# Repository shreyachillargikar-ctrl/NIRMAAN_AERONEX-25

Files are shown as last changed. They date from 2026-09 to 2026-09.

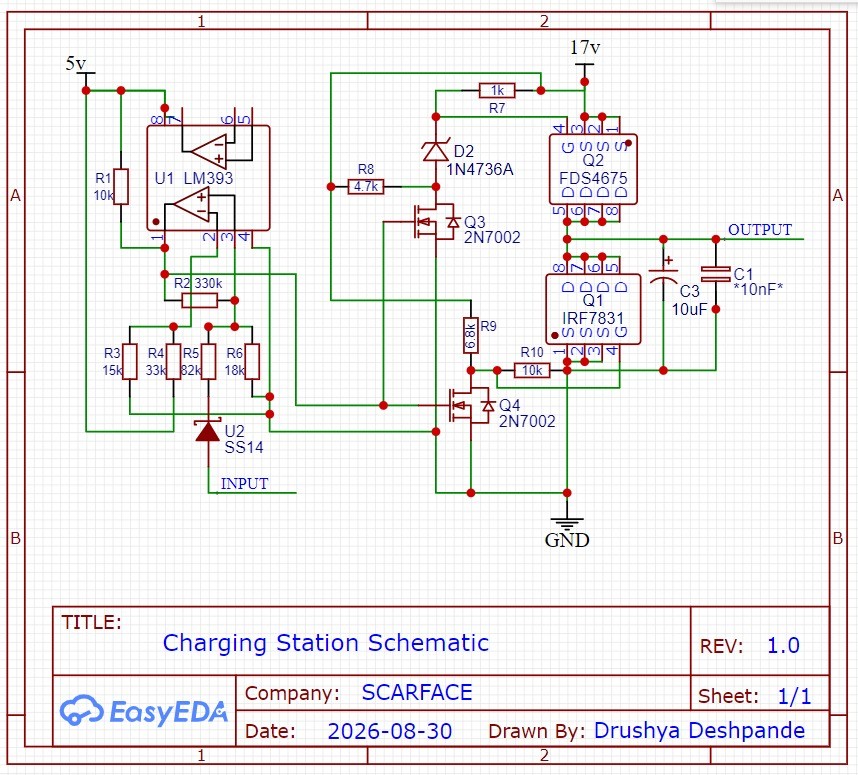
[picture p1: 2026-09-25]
Hardware/Circuit_Diagram/CIRCUIT DIAGRAM.jpeg

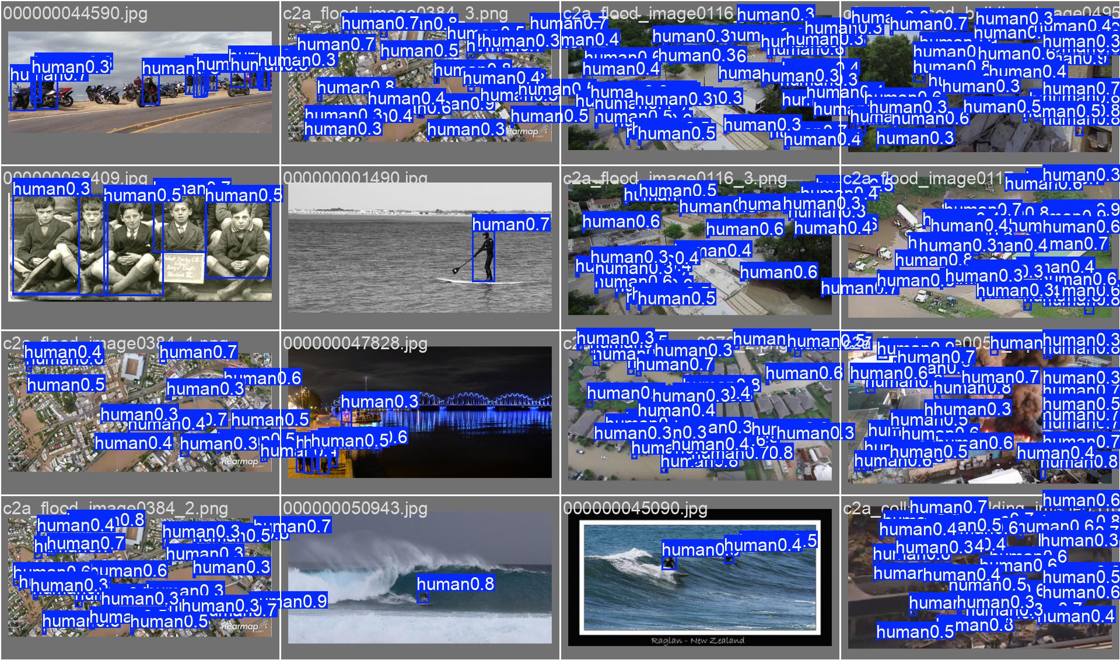
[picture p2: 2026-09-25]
Software/AI model/Trained_YOLOV8s/val_batch0_pred.jpg

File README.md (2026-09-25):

#  NIRMAAN_AERONEX-26

## AI-POWERED SEARCH AND RESCUE OPERATION DRONE

### NIRMAAN 2026
**Build. Innovate. Impact.**

---

##  TEAM INFORMATION

**Team Name:** NIRMAAN_AERONEX-26

**Team Leader:** ASHWATH YADAV

**Chosen Track:** Smart Mobility & Aerospace

**Problem Statement:**  
Development of an AI-powered aerial search and rescue system capable of assisting rescue teams in locating and identifying people in emergency and disaster situations.

---

# 1.  PROBLEM STATEMENT & REAL-WORLD IMPACT

## The Problem

During natural disasters, accidents, building collapses, floods, fires, and other emergency situations, locating people quickly can be difficult and dangerous.

Traditional search and rescue operations may require:

- Large numbers of rescue personnel
- Significant time to cover large areas
- Access to difficult or unsafe terrain
- Manual visual inspection
- Continuous communication between field teams

Areas with limited accessibility can significantly increase the time required to locate survivors.

### Why aerial assistance is required

A drone can provide:

- Rapid aerial coverage
- Access to difficult terrain
- Real-time aerial observation
- Reduced risk to human rescuers
- Faster identification of potential survivors

---

## Target Audience

The proposed system is intended to assist:

- Search and rescue teams
- Disaster response teams
- Emergency response organizations
- Fire and rescue departments
- Disaster management authorities
- Humanitarian response teams

---

## Current Gaps & Impact

### Current Gaps

Existing manual search operations can face:

- Limited area coverage
- Dependence on human visual inspection
- Difficult terrain accessibility
- Increased search time
- Risk to rescue personnel
- Difficulty maintaining continuous aerial surveillance

### Impact

AERONEX aims to support rescue operations by providing an aerial platform capable of:

**SEARCH → DETECT → LOCATE → REPORT**

This can help rescue personnel make faster and more informed decisions during emergency situations.

---

# 2. PROPOSED SOLUTION & INNOVATION

## Core Solution

AERONEX is an AI-powered search and rescue drone that combines:

- Autonomous flight
- GPS-based navigation
- Aerial imaging
- AI-based human detection
- Real-time telemetry
- Flight-controller-based stabilization
- Long-range radio communication

The drone is designed to autonomously navigate a defined search area while the onboard camera and AI processing system assist in identifying potential humans.

---

## Innovation Factor

The key innovation of AERONEX is the integration of an autonomous aerial platform with AI-based human detection for search and rescue applications.

Instead of relying entirely on manual visual inspection, the system is designed to assist in identifying potential survivors from aerial imagery.

### Innovation Highlights

- AI-assisted human detection
- Autonomous waypoint navigation
- GPS-based positioning
- Real-time telemetry
- Onboard mobile computing using a smartphone
- Integrated aerial surveillance
- Modular and scalable hardware architecture
- Customised Battery
- Automated charging Station 
---

# 3.  KEY FEATURES

###  Autonomous Navigation

The drone uses a flight controller and GPS system for autonomous waypoint-based navigation.

###  AI-Based Human Detection

The camera system provides aerial images/video for AI-based detection of people in the search area.

###  GPS Positioning

GPS provides location information required for navigation and mission planning.

###  Real-Time Telemetry

Telemetry enables communication between the ground station and the drone for monitoring flight and mission information.

###  Aerial Surveillance

The onboard camera provides an aerial view of the search environment.

###  Manual Override

The radio transmitter and receiver provide manual control capability when required.

###  Stable Flight Platfor

## System Architecture

```mermaid
flowchart TB

A[SEARCH AND RESCUE MISSION]
B[GROUND CONTROL STATION]
C[PIXHAWK 2.4.8 FLIGHT CONTROLLER]

A --> B
B -->|MISSION PLAN AND WAYPOINTS| C

D[NEO M10 GPS]
E[COMPASS]
F[IMU AND FLIGHT SENSORS]

D --> C
E --> C
F --> C

G[4 AIR GEAR 450 ESC]
H[4 920KV BLDC MOTORS]
I[4 T1045 PROPELLERS]

C -->|MOTOR CONTROL SIGNALS| G
G --> H
H --> I

J[CUSTOM LI ION BATTERY]
K[POWER DISTRIBUTION AND POWER MODULE]

J --> K
K --> C
K --> G
K --> L[ONEPLUS 6T]

L --> M[LIVE CAMERA FEED]
M --> N[AI COMPUTER VISION]
N --> O[HUMAN DETECTION]
O --> P[TARGET DETECTION]

Q[3DR 433 MHZ TELEMETRY]

C --> Q
P --> Q
Q <-->|TELEMETRY AND COMMANDS| B

P --> R[TARGET LOCATION]
R --> B
R --> C

C --> S[AUTONOMOUS NAVIGATION]
S --> T[NAVIGATE TO TARGET]
T --> U[SEARCH AND HOVER]
U --> V[MONITOR TARGET]
V --> W[RESCUE SUPPORT]

W --> B
B -->|UPDATED MISSION COMMANDS| C
```

---

## System Overview

OUR DRONE is an AI powered search and rescue operation drone integrating autonomous flight, GPS navigation, AI based human detection, real time telemetry and rescue support.

## MAIN SUBSYSTEMS

- Flight Control System
- Navigation System
- AI Search and Detection System
- Propulsion System
- Power Management System
- Communication System
- Ground Control System

---

## FLIGHT CONTROL SYSTEM

The Pixhawk 2.4.8 acts as the main flight controller.

It receives navigation and sensor information from the GPS, compass, and IMU and generates control signals for the ESCs.

### Components

| Component | Function |
|---|---|
| Pixhawk 2.4.8 | Flight control and autonomous navigation |
| NEO M10 GPS | Position and navigation |
| Compass | Heading information |
| IMU | Attitude and motion sensing |

### Flight Control Flow

```mermaid
flowchart LR

    GPS["NEO M10 GPS"]
    COMPASS["COMPASS"]
    IMU["IMU"]
    FC["PIXHAWK 2.4.8"]
    ESC["ESCs"]
    MOTOR["BLDC MOTORS"]

    GPS --> FC
    COMPASS --> FC
    IMU --> FC
    FC --> ESC
    ESC --> MOTOR
```

---

## NAVIGATION SYSTEM

The navigation system uses GPS, compass, and IMU information to support autonomous flight and position-based navigation.

```mermaid
flowchart TD

    GPS["NEO M10 GPS"]
    COMPASS["COMPASS"]
    IMU["IMU"]
    FC["PIXHAWK 2.4.8"]
    NAV["AUTONOMOUS NAVIGATION"]
    SEARCH["SEARCH AREA"]

    GPS --> FC
    COMPASS --> FC
    IMU --> FC
    FC --> NAV
    NAV --> SEARCH
```

---

## PROPULSION SYSTEM

The propulsion system converts electrical power into mechanical thrust.

```mermaid
flowchart LR

    FC["PIXHAWK 2.4.8"]
    ESC["4 x AIR GEAR 450 ESCs"]
    MOTOR["4 x 920KV BLDC MOTORS"]
    PROP["4 x T1045 PROPELLERS"]
    THRUST["THRUST"]

    FC --> ESC
    ESC --> MOTOR
    MOTOR --> PROP
    PROP --> THRUST
```

### Propulsion Components

| Component | Function |
|---|---|
| AIR GEAR 450 ESC | Controls motor speed |
| 920KV BLDC Motors | Generates rotational power |
| T1045 Propellers | Generates thrust |
| Pixhawk 2.4.8 | Provides motor control signals |

---

## AI SEARCH AND DETECTION SYSTEM

The OnePlus 6T is used for camera input and AI processing.

```mermaid
flowchart TD

    CAMERA["CAMERA"]
    PHONE["ONEPLUS 6T"]
    FEED["LIVE CAMERA FEED"]
    AI["AI COMPUTER VISION"]
    HUMAN["HUMAN DETECTION"]
    TARGET["TARGET INFORMATION"]

    CAMERA --> PHONE
    PHONE --> FEED
    FEED --> AI
    AI --> HUMAN
    HUMAN --> TARGET
```

---

## NAVIGATION AND TARGET FLOW

```mermaid
flowchart TD

    SENSORS["GPS + COMPASS + IMU"]
    FC["PIXHAWK 2.4.8"]
    NAV["AUTONOMOUS NAVIGATION"]
    AREA["SEARCH AREA"]
    AI["AI HUMAN DETECTION"]
    DETECT["TARGET DETECTED"]
    LOCATION["TARGET LOCATION"]
    MONITOR["SEARCH / HOVER / MONITOR"]
    RESCUE["RESCUE SUPPORT"]

    SENSORS --> FC
    FC --> NAV
    NAV --> AREA
    AREA --> AI
    AI --> DETECT
    DETECT --> LOCATION
    LOCATION --> MONITOR
    MONITOR --> RESCUE
```

---

## COMMUNICATION SYSTEM

The 3DR 433 MHz telemetry system provides communication between the drone and Ground Control Station.

```mermaid
flowchart LR

    GCS["GROUND CONTROL STATION"]
    COMMAND["MISSION COMMANDS"]
    TELEMETRY["3DR 433 MHz TELEMETRY"]
    FC["PIXHAWK 2.4.8"]
    STATUS["FLIGHT STATUS"]

    GCS --> COMMAND
    COMMAND --> TELEMETRY
    TELEMETRY --> FC

    FC --> STATUS
    STATUS --> TELEMETRY
    TELEMETRY --> GCS
```

---

## POWER MANAGEMENT SYSTEM

The custom Li-ion battery supplies power to the drone through the power distribution and power module.

```mermaid
flowchart TD

    BATTERY["CUSTOM LI ION BATTERY"]
    POWER["POWER DISTRIBUTION AND POWER MODULE"]
    FC["PIXHAWK 2.4.8"]
    ESC["ESCs"]
    MOTOR["BLDC MOTORS"]
    PHONE["ONEPLUS 6T"]

    BATTERY --> POWER
    POWER --> FC
    POWER --> ESC
    POWER --> PHONE
    ESC --> MOTOR
```

---

## GROUND CONTROL SYSTEM

The Ground Control Station communicates with the Pixhawk through 3DR telemetry.

```mermaid
flowchart LR

    OPERATOR["OPERATOR"]
    GCS["GROUND CONTROL STATION"]
    TELEMETRY["3DR 433 MHz TELEMETRY"]
    FC["PIXHAWK 2.4.8"]
    DRONE["AERONEX-25"]

    OPERATOR --> GCS
    GCS --> TELEMETRY
    TELEMETRY --> FC
    FC --> DRONE

    DRONE --> FC
    FC --> TELEMETRY
    TELEMETRY --> GCS
```

---

## POWER FLOW

```mermaid
flowchart TD

    BATTERY["CUSTOM LI ION BATTERY"]
    PDM["POWER DISTRIBUTION AND POWER MODULE"]

    FC["PIXHAWK 2.4.8"]
    ESC["ESCs"]
    MOTORS["BLDC MOTORS"]
    PHONE["ONEPLUS 6T"]

    BATTERY --> PDM
    PDM --> FC
    PDM --> ESC
    PDM --> PHONE
    ESC --> MOTORS
```

---

## OVERALL SYSTEM DATA FLOW

```mermaid
flowchart TD

    MISSION["MISSION"]
    GCS["GROUND CONTROL STATION"]
    TELEMETRY["3DR TELEMETRY"]
    FC["PIXHAWK 2.4.8"]

    NAV["AUTONOMOUS NAVIGATION"]
    SEARCH["SEARCH AREA"]

    CAMERA["CAMERA"]
    PHONE["ONEPLUS 6T"]
    AI["AI PROCESSING"]
    HUMAN["HUMAN DETECTION"]
    TARGET["TARGET INFORMATION"]

    ESC["ESCs"]
    MOTOR["BLDC MOTORS"]
    PROP["PROPELLERS"]
    THRUST["THRUST"]

    MISSION --> GCS
    GCS --> TELEMETRY
    TELEMETRY --> FC

    FC --> NAV
    NAV --> SEARCH

    SEARCH --> CAMERA
    CAMERA --> PHONE
    PHONE --> AI
    AI --> HUMAN
    HUMAN --> TARGET
    TARGET --> TELEMETRY

    FC --> ESC
    ESC --> MOTOR
    MOTOR --> PROP
    PROP --> THRUST
```

---

## MISSION WORKFLOW

```mermaid
flowchart TD

    START["MISSION START"]
    PLAN["MISSION PLANNING"]
    TAKEOFF["AUTONOMOUS TAKEOFF"]
    NAV["GPS BASED NAVIGATION"]
    SEARCH["SEARCH OPERATION"]
    CAMERA["CAMERA CAPTURE"]
    AI["AI PROCESSING"]
    DETECT{"HUMAN DETECTED?"}
    MONITOR["HOVER / MONITOR TARGET"]
    REPORT["SEND TARGET INFORMATION"]
    RESCUE["RESCUE SUPPORT"]
    RETURN["RETURN / MISSION COMPLETION"]

    START --> PLAN
    PLAN --> TAKEOFF
    TAKEOFF --> NAV
    NAV --> SEARCH
    SEARCH --> CAMERA
    CAMERA --> AI
    AI --> DETECT

    DETECT -->|NO| SEARCH
    DETECT -->|YES| MONITOR
    MONITOR --> REPORT
    REPORT --> RESCUE
    RESCUE --> RETURN
```

---

## MAIN HARDWARE COMPONENTS

| Component | Purpose |
|---|---|
| Pixhawk 2.4.8 | Flight controller |
| NEO M10 GPS | Position information |
| Compass | Heading information |
| IMU | Attitude and motion sensing |
| OnePlus 6T | Camera and AI computing |
| AIR GEAR 450 ESC | Motor speed control |
| 920KV T Gear Motors | Drone propulsion |
| T1045 Propellers | Thrust generation |
| Custom Li-ion Battery | Power source |
| Power Distribution / Power Module | Power distribution |
| 3DR 433 MHz Telemetry | Communication |

---

## KEY FEATURES

- AI-powered human detection
- Autonomous flight
- GPS-based navigation
- Real-time telemetry
- Ground Control Station communication
- Onboard camera and AI processing
- Autonomous search and monitoring
- Target detection
- Rescue support
- Integrated propulsion and power system

---

## PROJECT OBJECTIVE

The objective motive is to provide an aerial platform capable of assisting search and rescue operations by combining autonomous flight, AI-based human detection, aerial surveillance, and real-time communication.

The system is designed to support search teams by providing aerial observation and target information over search areas.

---

---

## PROJECT SUMMARY

**Project Name:** NIRMAAN_AERONEX-25

**Project Type:** AI Powered Search and Rescue Operation Drone

**Platform:** Autonomous Quadcopter

**Flight Controller:** Pixhawk 2.4.8

**AI Computing:** OnePlus 6T

**Communication:** 3DR 433 MHz Telemetry

**Navigation:** NEO M10 GPS + Compass + IMU

**Propulsion:** 4 × 920KV T Gear Motors + 4 × T1045 Propellers

**ESC:** 4 × AIR GEAR 450 ESCs

---

## CONCLUSION

OUR DRONE integrates autonomous flight, GPS navigation, AI-based human detection, onboard computing, telemetry, propulsion, and power management into a unified aerial search and rescue platform.

The modular architecture allows the major subsystems to work together for autonomous search, human detection, monitoring, and rescue support.

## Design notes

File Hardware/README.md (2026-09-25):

# AERONEX Hardware

Hardware components used in the AERONEX AI-powered search and rescue quadcopter.

## Flight Controller
- Pixhawk 2.4.8

## Propulsion System
- 4 × 920KV
- 4 × ESCs AIR GEAR 450
- 4 × Propellers T1045

## Power System
- CUSTOM LI-ION BATTERY
- Power Distribution / Power Module

## Navigation
- GPS Module-NEO M10
- Compass 

## Communication
- Telemetry Module 3DR 433mhz
- Flysky Radio Transmitter and Receiver

## AI & Payload
- AI Object Detection- Yolov8
- Search and Rescue Payload

## Mechanical Structure
- Quadcopter Frame
- Landing Gear
- Payload Mount

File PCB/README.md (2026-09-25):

# AERONEX PCB

PCB designed for the AERONEX AI-powered search and rescue drone.

## Purpose

The PCB is designed for power distribution and electrical interfacing of the drone hardware.

## PCB Files

- PCB design files
- PCB layout
- Schematic
- PCB images

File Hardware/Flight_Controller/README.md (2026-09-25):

# AERONEX Flight Controller

This folder contains the flight controller hardware and firmware documentation for the AERONEX AI-powered search and rescue drone.

## Flight Controller

- Pixhawk 2.4.8
- ArduPilot firmware
- Mission Planner
- GPS and telemetry support

## Purpose

The flight controller is responsible for stabilization, navigation, autonomous flight, GPS-based positioning, and communication with the ground control station.

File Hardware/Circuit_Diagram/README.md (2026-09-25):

# Circuit Diagram

Circuit and wiring diagrams for the AERONEX search and rescue quadcopter.

## Main Systems
- Pixhawk 2.4.8
- ESC and motor connections
- GPS and compass
- Telemetry
- Power distribution

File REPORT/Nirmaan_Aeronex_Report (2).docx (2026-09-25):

TECHNICAL REPORT

NIRMAAN 2026

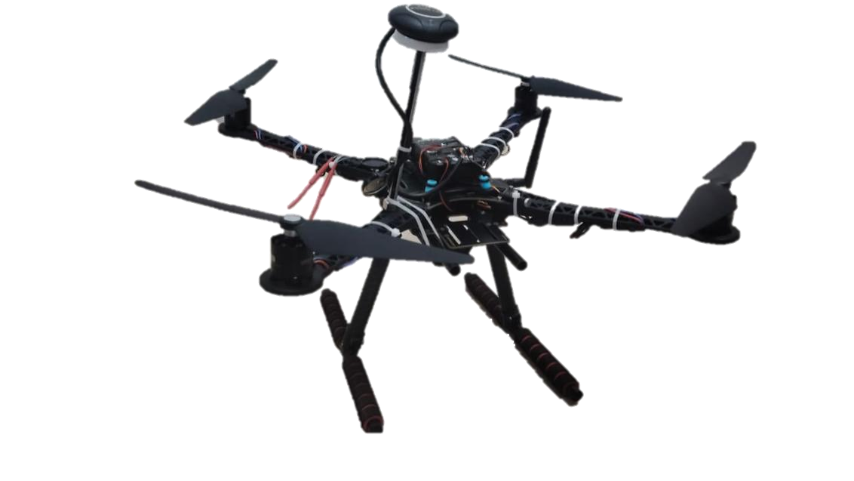
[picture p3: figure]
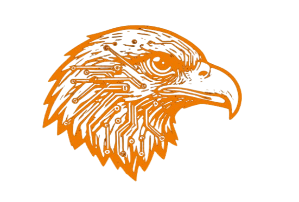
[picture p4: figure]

AERONEX

Problem Statement Title - A deployable Al-powered autonomous drone that aids search-and-rescue operations by detecting people and hazards, thereby Improving responder safety and reducing victim discovery time.

Table of Contents

### 1.0 Introduction.....................................................................................2

### 1.1 Objectives…………….......................................................................... 3

### 1.2 MissionProfile................................................................................. 3

### 2.0 Conceptualization and Design Selection Process.............................. 3

### 3.0 Preliminary Weight Estimation........................................................ 5

### 3.1 Selection of Propulsion System....................................................... 5

3.1.1 Selection of Motor........................................................................ 5

3.1.2 Battery and Endurance Estimation……………………....……………………. 6

### 3.2 Avionics Subsystem Selection.......................................................... 8

3.2.1 Selection of Flight Controller......................................................... 8

3.2.2 Selection of Flight Computer......................................................... 9

3.2.3 Navigation System....................................................................... 9

4.0 Bill of Materials ............................................................................. 9

5.0 Autonomous Flight Simulation ...................................................... 13

6.0 Innovations ...................................................................................11

7.0 Safety Measures ........................................................................... 21

8.0 Conclusion .................................................................................... 22

# 1.0 Introduction

# 1.1 Objectives

The Internal Smart India Hackathon 2026 requires the team to design, develop, and demonstrate an Unmanned Aerial Vehicle (UAV) capable of autonomous mission execution for real-world payload delivery tasks. The team focuses on achieving high efficiency, low navigation and control error, and robust flight stability while maintaining practical manufacturability and commercial viability of the platform.

1.2 Mission profile:

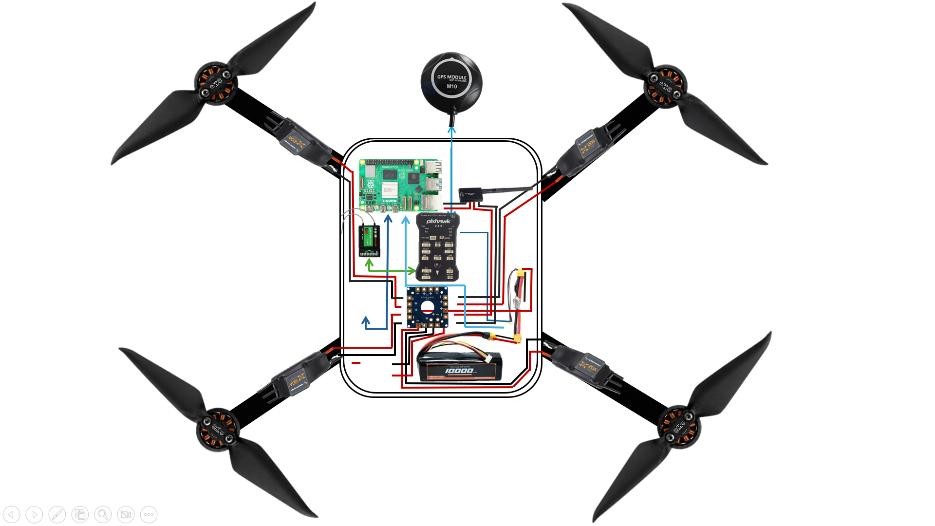
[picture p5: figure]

The autonomous UAV is made for detection of living creatures which stuck in flood, waiting for rescue and medication. Our UAV can search them and give their geotag location or provide a first aid kit. Rescuers can continuously monetize the mission’s live feed.

# 2.0 Conceptualization and Design Selection Process

In the early design phase, the team reviewed relevant UAS literature and shortlisted feasible multirotor layouts. A structured Pugh chart evaluation was then used to compare configurations against key parameters and select the most suitable frame for the mission.

Parameters | Score(/5) | Quad X | | Quad+ | | Quad H | | Hexacopter
| | Score | Total | score | Total | score | Total | Score | Total
Stability | 5 | 4 | 20 | 3 | 15 | 4 | 20 | 5 | 25
Power Consumption | 2 | 4 | 8 | 4 | 8 | 3 | 6 | 2 | 4
Manufacturability | 3 | 4 | 12 | 4 | 12 | 3 | 12 | 2 | 6
Manoeuvrability | 3 | 5 | 15 | 2 | 6 | 4 | 12 | 2 | 6
Fragile Payload Drop | 5 | 5 | 25 | 3 | 15 | 4 | 20 | 4 | 20
Total | | | 80 | | 56 | | 70 | | 61

-: Comparison Table for Multirotor :-

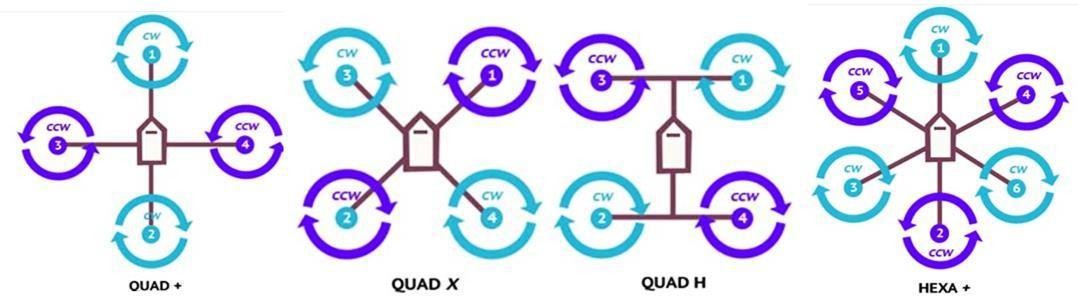
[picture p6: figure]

-: Types of Multirotor Configuration :-

# 3.0 Preliminary Weight Estimation

Components | Weight approximation(kg)
UAV frame | 0.47
Motors | 0.25
ESC’s | 0.084
Battery | 0.590
Flight controller + computer | 0.14
Telemetry + Receiver + GPS module | 0.087
Auxiliary weight | 0.17
Total UAV Weight | 1.791

# 3.1 Selection of Propulsion System

## 3.1.2 Selection of Motor

Motors are critical components of a UAV in analysing performance and its potential under various circumstances. For selection of optimal motor, the essential parameters are listed in Table 5 which shows the comparison of various motors.

Motor | Weight (g) | Voltage (V) | Current (A) | Power (W) | Thrust (g) | Propeller (inch) | Efficiency (g/W)
T-motor MN3110700kv | 99 | 16.8 | 14.0 | 235.2 | 1290 | 12*4.5 | 5.48
Emax ECOII22072400kv | 33.5 | 16.8 | 41.8 | 702.24 | 1610 | 5*5 | 2.29
T-motor Air gear 450II920kv | 62 | 16.8 | 16.3 | 260 | 1332 | 10*4.5 | 5.3
Sunnysky A2212980kv | 56 | 16.8 | 16.6 | 278.88 | 1220 | 9*4.5 | 4.37

Considering key parameters and the manufacturers’ datasheet, T-motor Air-gear 450II 920Kv motor paired with 10*4.5 inches propeller was selected. Additionally, to ensure the safe current regulations of motor without affecting the motors speed. The team decided to choose HobbyWing 20A ESC. It is known for its extensive safety features, including low-voltage cutoff, thermal protection and signal loss protection, which assures safe operation and efficient power management by reducing heat buildup and extending run time.

## 3.1.3 Battery and Endurance Estimation

Battery selection is driven by a quantitative assessment of total system power demand, accounting for operating voltage and current drawn across all subsystems during critical conditions. The overall on-board power requirement is determined by aggregating the power consumption of each subsystem, enabling an optimized power system design for improved performance and flight endurance.

Table: Power Consumption of each component

Components | Power Consumed
| Power(W) | Quantity | Total power(W)
Motors | 260 | 4 | 1040
Flight Controller | 15 | 1 | 15
On-board Flight Computer | 25 | 1 | 25
Total | | | 1080

#### Capacity = Total Power (W) × Time (h) - Capacity = 1080 × 0.25 = 270 Wh

Operating at a nominal voltage of 14.8 V (4S 2P configuration) required battery capacity is derived using an energy-balance model accounting for motor load, miscellaneous power, flight duration, and thrust-to-weight ratio:

((P × 4) + M) × t) ((260 × 4) + 40) × 0. 25

C = − −(2) C = = 7. 415Ah

V × (T/W) 14. 8 × (2. 46)

where, V=Voltage, P=Power at 100% throttle, C=Battery capacity, M=Miscellaneous power, t=Time in hours, T/W =Thrust-to-weight ratio

Table 8: Current consumed by individual components.

Components | Current Drawn
| Current (A) | Quantity | Total current(A)
Motors | 16.3 | 4 | 65.2
Flight Controller | 3 | 1 | 3
On-board Flight Computer | 5 | 1 | 5
Total | | | 73.2

The combined current demand across all subsystems is 73.2A With an estimated battery requirement of 7415 mAh .The minimum required continuous discharge rate is therefore :

I 73.2

C-rating = C-rating = = 9.87C

C 7.415

Where I=Total Current, C=Battery Capacity

# 3.2 Avionics Subsystem Selection

## 3.2.1 Selection of Flight Controller

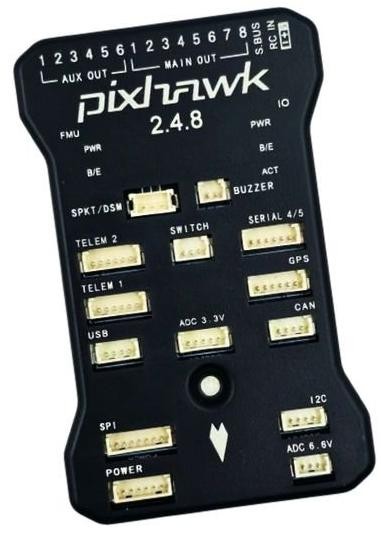
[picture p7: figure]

The flight controller, the Pixhawk 2.4.8 is the embedded control unit of your UAV. The flight controller stabilises the UAV guides it and manages the aircraft in time. The flight controller receives data from sensors such as the IMU (accelerometer and gyroscope) magnetometer, barometer and GPS.

The flight controller fuses this data. Runs flight-control algorithms. The flight controller constantly calculates the attitude, angular rates, position and altitude corrections. The flight controller then creates PWM, for the four ESCs based on the Quad-X motor mixing rules so that the UAV can adjust roll, pitch, yaw and thrust separately. The flight controller also handles arming and disarming failsafe logic, flight modes, battery monitoring, parameter management GPS navigation and autonomous missions.

## 3.2.2 Selection of Flight Computer

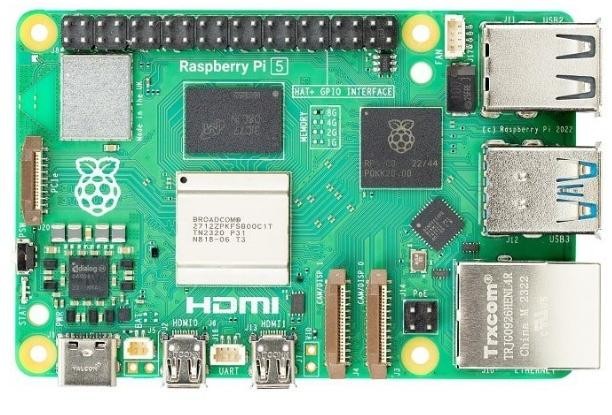
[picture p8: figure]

The Flight Computer is used as the companion computer. It works with the Pixhawk 2.4.8. It provides level computational capabilities such as computer vision, AI/YOLO object detection, autonomous path planning, sensor processing, missionlevel decision making. These tasks are beyond the real-time flight-control capabilities of the Pixhawk.

The RPI5 can communicate with the Pixhawk through MAVLink over UART. It uses software such as MAVSDK. It sends high-level commands such as arm, takeoff, waypoint navigation, velocity commands and landing. The Pixhawk handles the low-level attitude stabilization, motor mixing, PID control loops, sensor fusion and actuator outputs

## 3.2.3 Navigation System

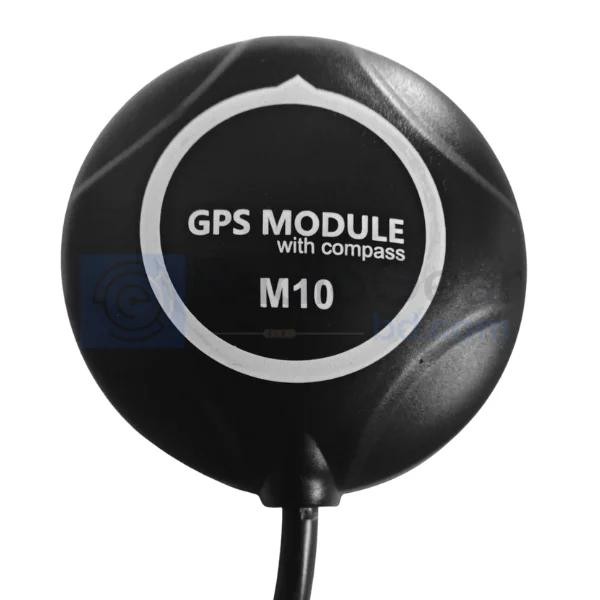
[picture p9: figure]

The M10 GNSS navigation system provides the drone with position, speed, height and time information derived from signals received from global navigation satellite constellations such as GPS, Galileo, GLONASS and BeiDou.

The M10 GNSS navigation system supplies latitude, longitude and height coordinates along with ground speed to the Pixhawk 2.4.8.

There the M10 GNSS navigation system data is merged with IMU readings and other sensor measurements through EKF sensor fusion to produce an estimate of the drone’s state. The M10 GNSS navigation system is crucial for tasks such, as holding position returning to launch following waypoints

carrying out missions respecting geofences and performing precise outdoor navigation. Additionally the M10 GNSS navigation system offers a position reference allowing the flight controller to correct any drift.

# 4.0 Bill of Materials

Based on the specifications the team has decided on the cost breakdown for both electronic and mechanical components as shown in the Table 9 and 10 respectively.

### Components Rate (Rs.) Quantity Total Amount (Rs)

T Motors Air Gear 450 Combo 1800 4 7200

Flysky FS-i6S Transmitter 4988 1 4988

Flight Controller 6929 1 6929

FS-iA10B 10CH Receiver | 2019 | 1 | 2019
Neo M10 GPS | 2589 | 1 | 2589
GPS Stand / Holder | 289 | 1 | 289
Telemetry | 6853 | 1 | 6853
Custom Li-ion battery | 481 | 8 | 3848
Drone Frame Kit | 3379 | 1 | 3379
Power Module | 579 | 1 | 579

Total Components Amount = 38673

5.0 Autonomous Flight simulation

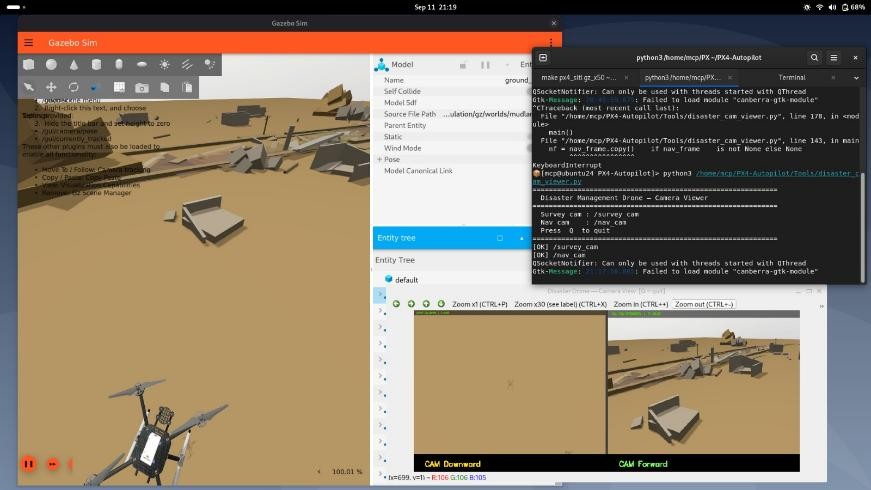
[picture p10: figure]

The autonomous UAS mission was simulated using Gazebo as the primary 3D simulation environment to support the development and validation of the autonomous aerial system.

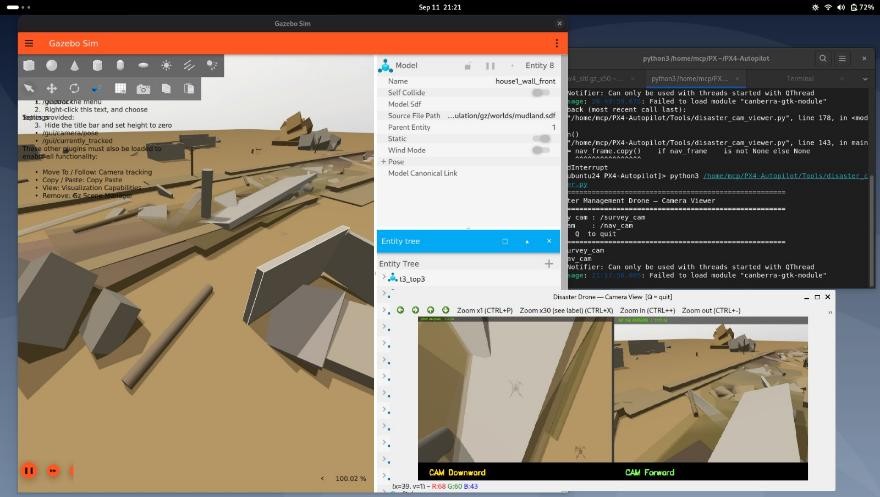
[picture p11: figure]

The complete autonomous mission logic was executed through a MAVSDK-Python–based control architecture, where the mission script handled navigation, waypoint management, replanning, and mission-state transitions.

The UAS flight dynamics were simulated using PX4 Software-in-theLoop (SITL), enabling realistic interaction between the virtual drone and the MAVSDK-based mission system through MAVLink communication.

➢ Selection of Radio Telemetry

Radio telemetry enables data transmission between the quadcopter and ground control station using electromagnetic waves. Through the MAVLink protocol, it relays real-time information such as altitude, speed, battery status, and GPS position, allowing the pilot to monitor the vehicle and adjust flight parameters efficiently. For control, the team utilizes the Radiomaster Flysky FS-i6S 2.4GHz 10CH AFHDS 2A RC Transmitter paired with the FS-iA10B 10CH Receiver, providing a range of up to 1.5 km at 2.4 GHz. Additionally, the 3DR Radio Telemetry module is employed for communication, offering an approximate range of 2.5 to 3 km at 915MHz.

➢ Specification of the Radio Telemetry

Modulation Type | GFSK
Band-Range(GHz) | 2.4-2.48
Sensitivity (dBm) | 105dbm (Receiver)
Band-width (KHz) | 500
Operating-Voltage (VDC) | Receiver: 5V; Transmitter: 12V;
Antenna Length (mm) | 26
Code type | Digital
DSC Port | PS/2 Port PPM
RF Power | Less than 20 dbm
Dimensions (mm) L*W*H | 179*161*81
Weight | Tx: 410 gm Rx: 15 gm
No. of Channels | 6
Low Voltage Warning | Yes (at less than 9V)
Charging Port | Yes

6.0 Innovation

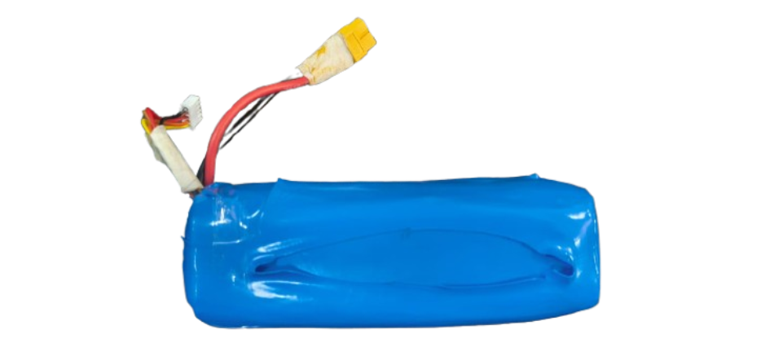
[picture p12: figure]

### 1. Custom battery

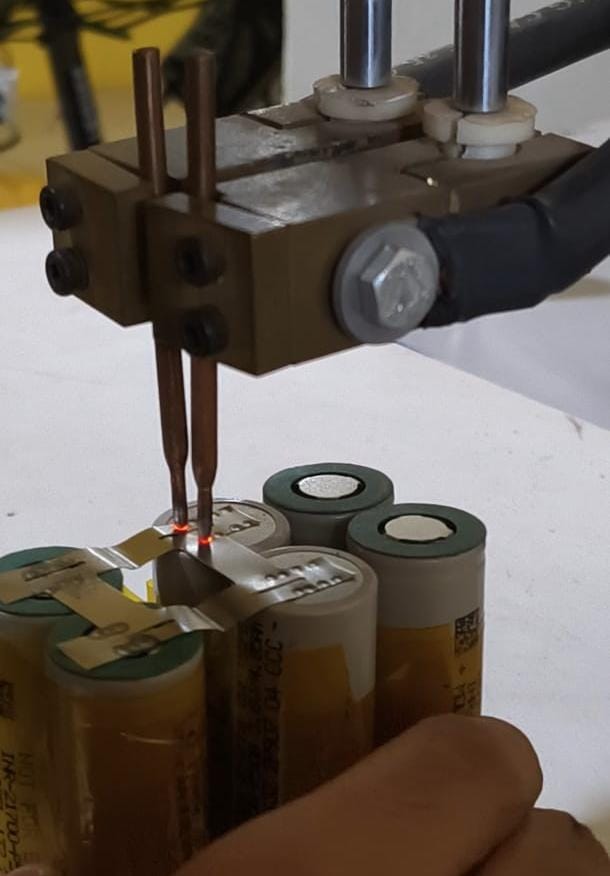
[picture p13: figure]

A custom 4S2P battery pack was designed and fabricated using Molicel INR-21700-P45B cells, delivering a nominal voltage of 14.8V, a capacity of 9Ah, and a peak discharge rate of 10C — all under 600g, offering a superior gravimetric energy density compared to most commercially available drone batteries.

This custom battery gives 18.5 mins of flight time.

### 2. Custom motor driver

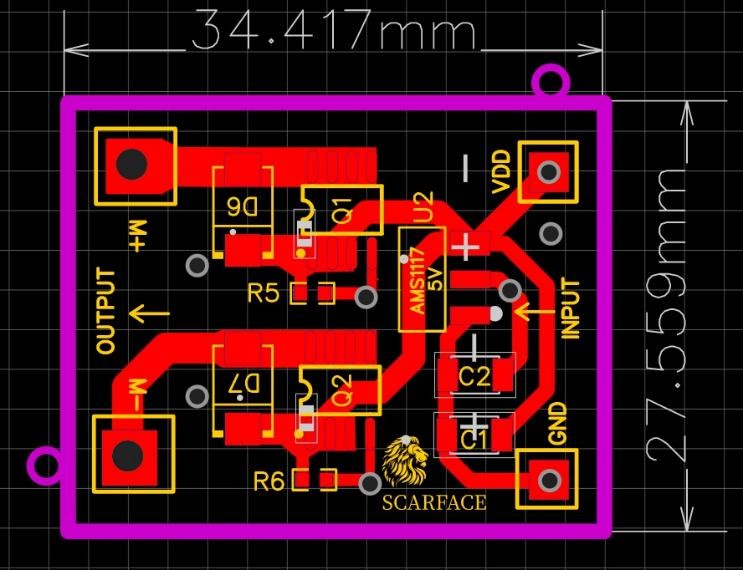
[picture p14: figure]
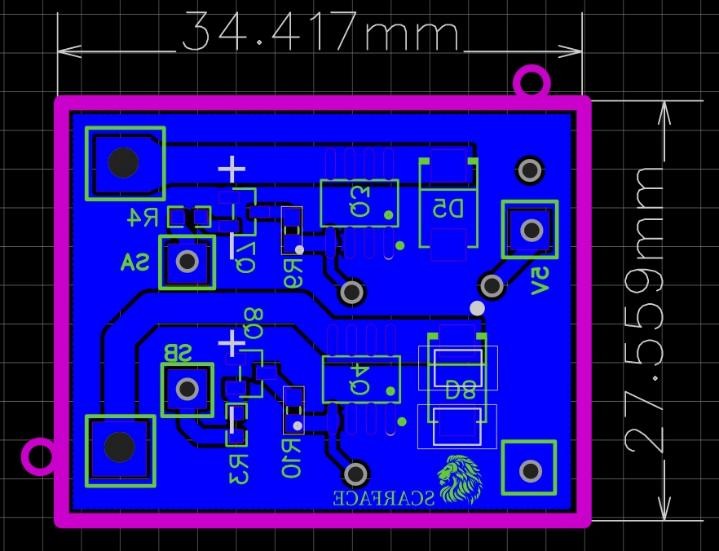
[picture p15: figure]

To enable precise payload deployment and retrieval, an electromechanical pulley-based actuation system was developed as a controlled alternative to conventional single-use drop mechanisms. A DC motor coupled to a pulley provides bidirectional torque for deterministic lowering and retraction of the payload, improving positional accuracy and repeatability across successive operations.

The custom motor driver was designed in place of a commercial motor drivers to meet the specific current requirements of the DC motor. The driver implements a MOSFET-based H-bridge topology with a modified servo interface, enabling direct PWM acquisition from the flight controller and translating control signals

into discrete switching states for bidirectional motor operation. High-side P-channel and low-side N-channel MOSFETs facilitate efficient polarity reversal across the motor terminals, while integrated flyback diodes clamp inductive voltage transients during commutation, protecting the switching devices from overvoltage stress.

This architecture minimises component overhead and reduces board space and mass compared to commercially available alternatives — delivering a compact, tightly integrated actuation solution well-suited for weight-sensitive quadcopter applications.

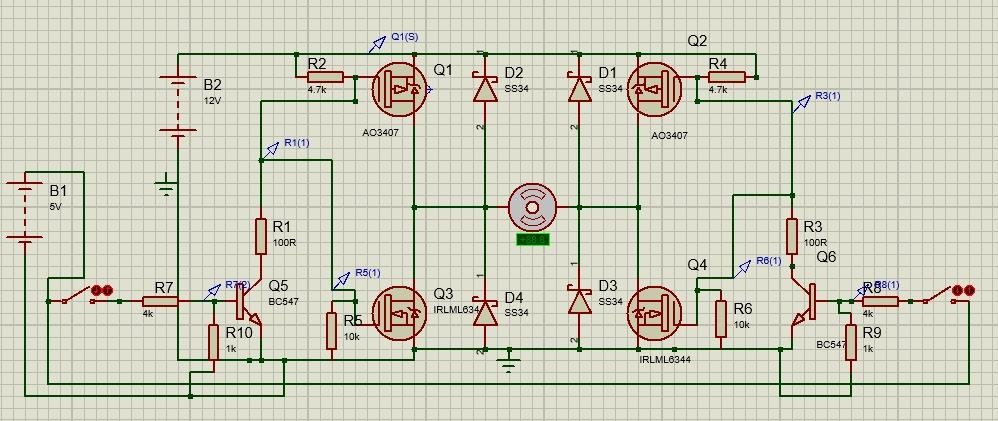
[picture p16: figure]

Custom Automatic Charging Station

Each grid cell uses an independent MOSFET-based switching circuit to connect the cell to either +17 V or GND according to the detected landing condition. The LM393 comparator generates the control signal, while 2N7000 N MOSFETs drive the power MOSFETs. IRF4905 acts as the high-side switch for +17 V, while Q1 IRFZ44N acts as the low-side switch for GND.

The PMOS gate is biased and protected using a Zener-diode clamp, which limits the gatesource voltage to a safe value. The NMOS gate is biased using a resistor voltage divider, providing the required gate voltage while keeping the NMOS OFF by default before drone landing.

The identical per-grid circuits form a modular charging architecture, allowing the station to be foldable, portable, and easy to maintain, with each grid independently switched according to the drone’s landing configuration.

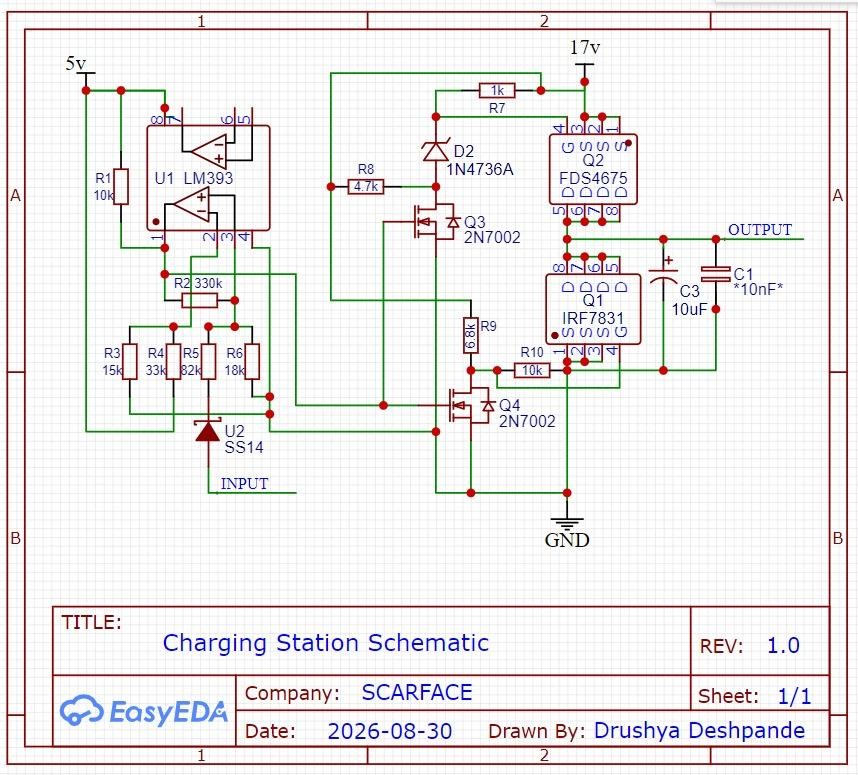
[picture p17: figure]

Charging Station Schematic

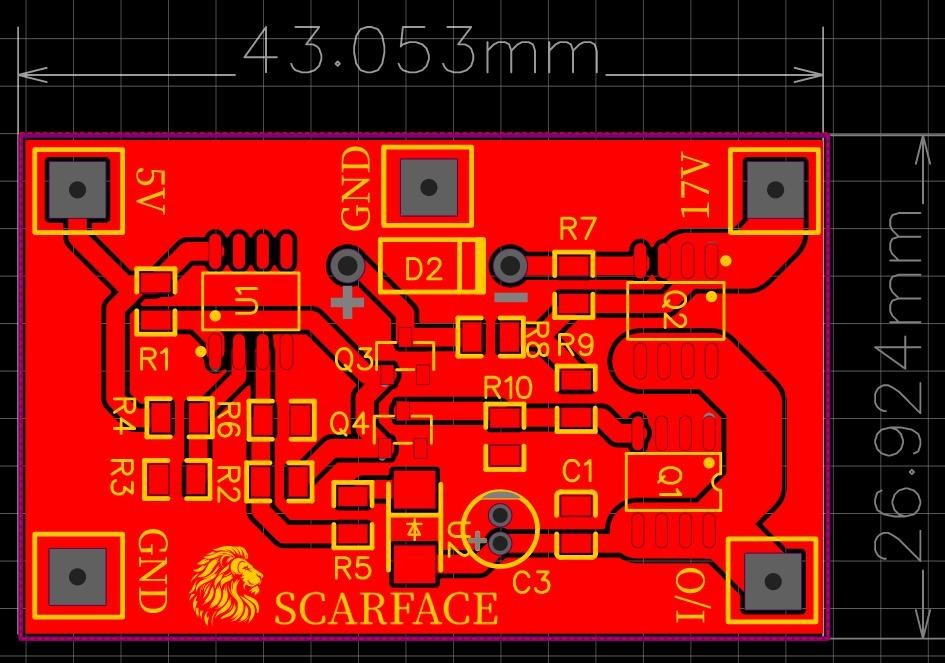
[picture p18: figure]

PCB design of charging station (SMD version)

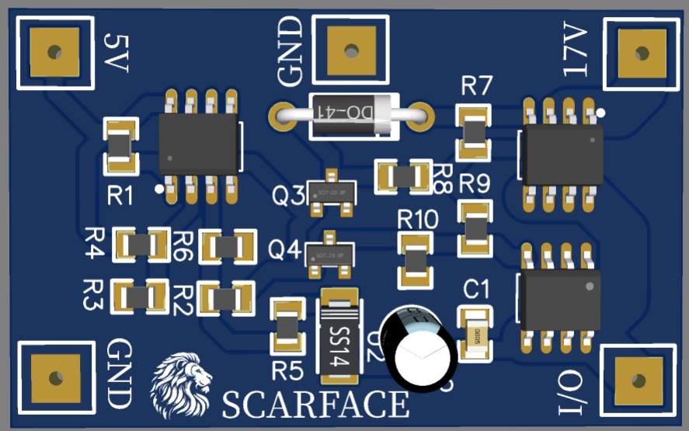
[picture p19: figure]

3D view : PCB design of charging station (SMD version)

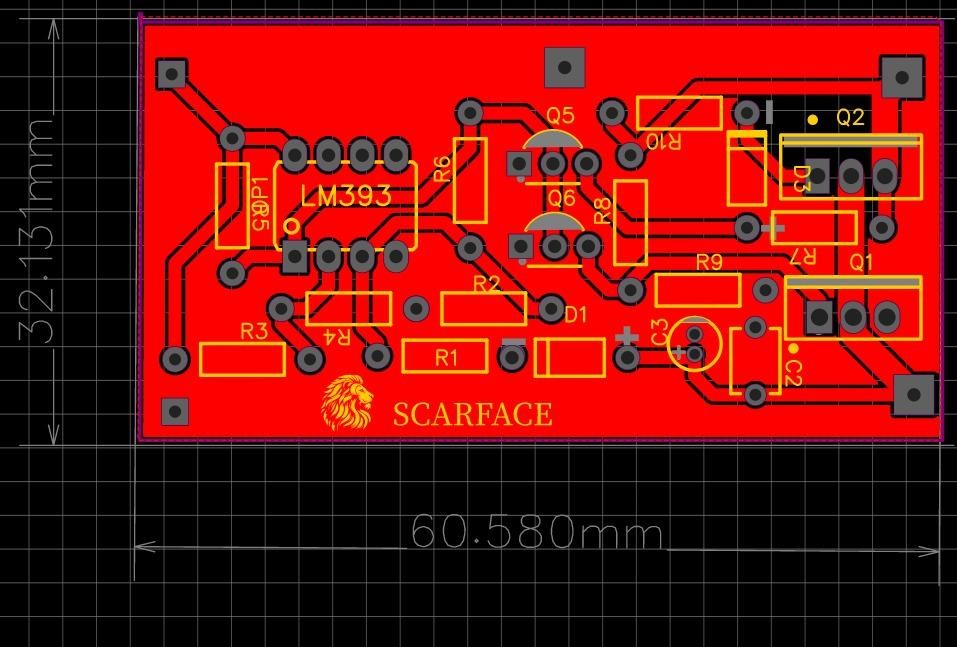
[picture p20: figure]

PCB design of charging station (THT version)

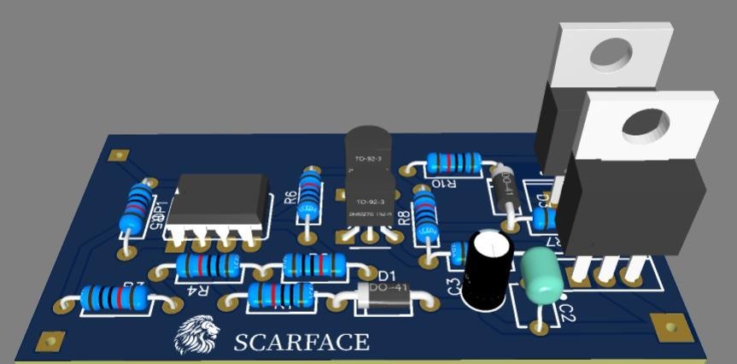
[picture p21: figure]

3D view : PCB design of charging station (THT version)

Given Values

Parameter | Value
LM393 supply | VCC = 5 V
R1 | 10 kΩ
R2 (feedback) | 330 kΩ
R3 | 15 kΩ
R4 | 33 kΩ
R5 | 82 kΩ
R6 | 18 kΩ
Maximum input | 16.8 V
Assumed diode drop | VD ≈ 0.7 V

### 1. Reference Voltage at Pin 2

R4 and R3 form the reference divider.

VREF = (VCC × R3)/((R3 + R4))

VREF = (5 × 15k)/((15k + 33k))

VREF = (5 × 15)/48

VREF = 1.5625 V

Therefore, Pin 2 = 1.5625 V.

### 2. Reference-Divider Current

IREF = VCC / (R3 + R4)

IREF = 5 / 48k

IREF = 104.17 µA

### 3. Input Voltage After D1

Assuming D1 has a forward voltage of approximately 0.7 V:

VIN,D1 = VIN − VD At VIN = 16.8 V:

VIN,D1 = 16.8 − 0.7 = 16.1 V

### 4. Pin 3 Signal Voltage

Ignoring the feedback effect of R2 for this initial signal calculation:

V3 = VIN,D1 × R6 / (R5 + R6)

V3 = 16.1 × 18k / (82k + 18k)

V3 = 16.1 × 18 / 100

V3 = 2.898 V

Thus, at 16.8 V input, the divider signal is approximately 2.898 V.

### 5. Feedback Resistor R2 and Switching Threshold

R2 = 330 kΩ provides positive feedback from the LM393 output to Pin 3, creating hysteresis and two switching thresholds.

At the exact switching point, the comparator inputs are equal:

V3 = V2 = VREF = 1.5625 V

Therefore, 1.5625 V is used for V3 in the threshold calculation. The 2.898 V value is the Pin-3 divider voltage at 16.8 V input when the R2 feedback effect is ignored.

### 6. Upper Threshold — Input Rising

When the LM393 output is LOW, VOUT ≈ 0 V.

(VIN,D1 − VREF)/R5 + (VOUT − VREF)/R2 = VREF/R6 (VIN,D1 − 1.5625)/82k + (0 − 1.5625)/330k = 1.5625/18k Solving gives VIN,D1 ≈ 9.07 V. VIN(UPPER) = 9.07 + 0.7 ≈ 9.77 V Upper threshold ≈ 9.77 V.

### 7. Lower Threshold — Input Falling

When the LM393 output is HIGH, VOUT ≈ 5 V.

(VIN,D1 − VREF)/R5 + (VOUT − VREF)/R2 = VREF/R6

(VIN,D1 − 1.5625)/82k + (5 − 1.5625)/330k = 1.5625/18k

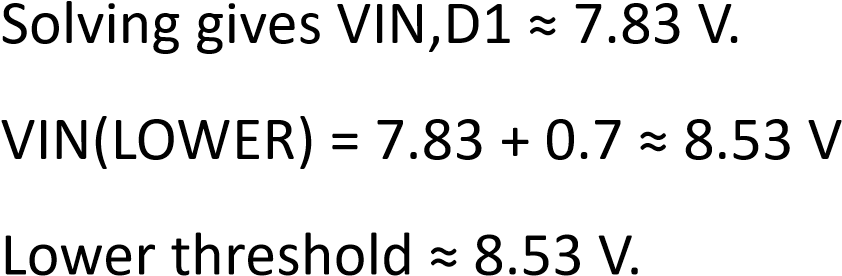
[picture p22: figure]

### 8. Hysteresis Voltage

VH = VTH(UPPER) − VTH(LOWER)

VH = 9.77 − 8.53

VH ≈ 1.24 V

Feedback Resistor Calculation

The following calculation is added from the handwritten calculation provided.

### 1. Feedback Resistor Calculation

The feedback resistor can be estimated using the required hysteresis voltage:

Rf = R1 × (VOH − VOL) / ΔV

Using R1 = 82 kΩ, VOH = 5 V, VOL ≈ 0 V, and ΔV = 1.21 V:

Rf = 82 × 10³ × 5 / 1.21

Rf ≈ 338.84 × 10³ Ω

Rf ≈ 330 kΩ

Therefore, a standard 330 kΩ resistor is a practical selected value.

### 2. Voltage Contribution with 330 kΩ Feedback Resistor

Using the selected 330 kΩ feedback resistor, the approximate voltage contribution is:

ΔV ≈ R1 × VOH / Rf

ΔV ≈ 82 kΩ × 5 V / 330 kΩ

ΔV ≈ 1.24 V

Thus, the 330 kΩ feedback resistor produces approximately 1.24 V of hysteresis contribution, which is close to the required 1.21 V.

### Final Results

Parameter | Value
Reference voltage, Pin 2 | 1.5625 V
Reference-divider current | 104.17 µA
Pin 3 at 16.8 V input (without R2 feedback) | 2.898 V
Upper input threshold | ≈ 9.77 V
Lower input threshold | ≈ 8.53 V
Hysteresis | ≈ 1.24 V

Note: Thresholds assume D1 ≈ 0.7 V and LM393 HIGH output ≈ 5 V. Actual values can vary with diode forward voltage and output behavior.

# 7.0 Safety Measures

Failsafe Mechanism | Trigger Condition | System Response / Action
Battery Failsafe | The system triggers when voltage drops below the threshold or capacity falls below 20%. | The drone executes Return to Launch (RTL) to land safely before power is depleted.
RC Failsafe | It activates if the transmitter signal is lost for more than 1 second. | The flight controller switches to RTL mode to return the vehicle to the home point.
Geofence Failsafe | This triggers if the UAV breaches the pre- | The system motion immediately and executes an RTL command.
| defined altitude or radius boundaries.
GCS Failsafe | It activates upon the sustained loss of the telemetry link with the ground station. | The drone initiates RTL or lands to ensure it remains within a recoverable range.

# 8.0 Conclusion

Based on the technical report the proposed system uses a Quad-X UAV platform with a Pixhawk 2.4.8 flight controller, a Raspberry Pi 5 companion computer, a Neo M10 GNSS module, MAVLink/MAVSDK communication and PX4 SITL–Gazebo simulation to perform autonomous search-and-rescue operations. The T-Motor Air Gear 450II 920KV propulsion system paired with 10×4.5-inch propellers delivers thrust to support the 1.791 kg UAV while the custom 4S2P Molicell INR-21700P45B battery ensures about 18.5 minutes of flight time.

The Pixhawk handles real-time attitude stabilization, sensor fusion, PID control, motor mixing, navigation and failsafe functions. The Raspberry Pi 5 adds capabilities such as computer vision, YOLO-based object detection, path planning and mission-level decision making. The M10 GNSS provides position, velocity and altitude data for EKF-based state estimation and autonomous navigation.

Autonomous mission logic was tested using PX4 Software-in-the-Loop and Gazebo simulations with MAVSDK-Python managing waypoint navigation,

replanning and transitions between mission states. A custom electromechanical pulley system enables controlled and repeatable delivery of first-aid supplies. The custom MOSFET H-bridge motor driver allows actuation, with minimal mass and power consumption.

A custom automatic charging station supports autonomous operation through a comparator-controlled MOSFET switching circuit and hysteresisbased battery detection. In total this system brings together flight control, GNSS navigation onboard AI perception, mission planning, payload deployment, telemetry and automated recharging into one integrated UAV solution. The goal is to reduce victim discovery time and enhance responder safety during search-and-rescue missions.

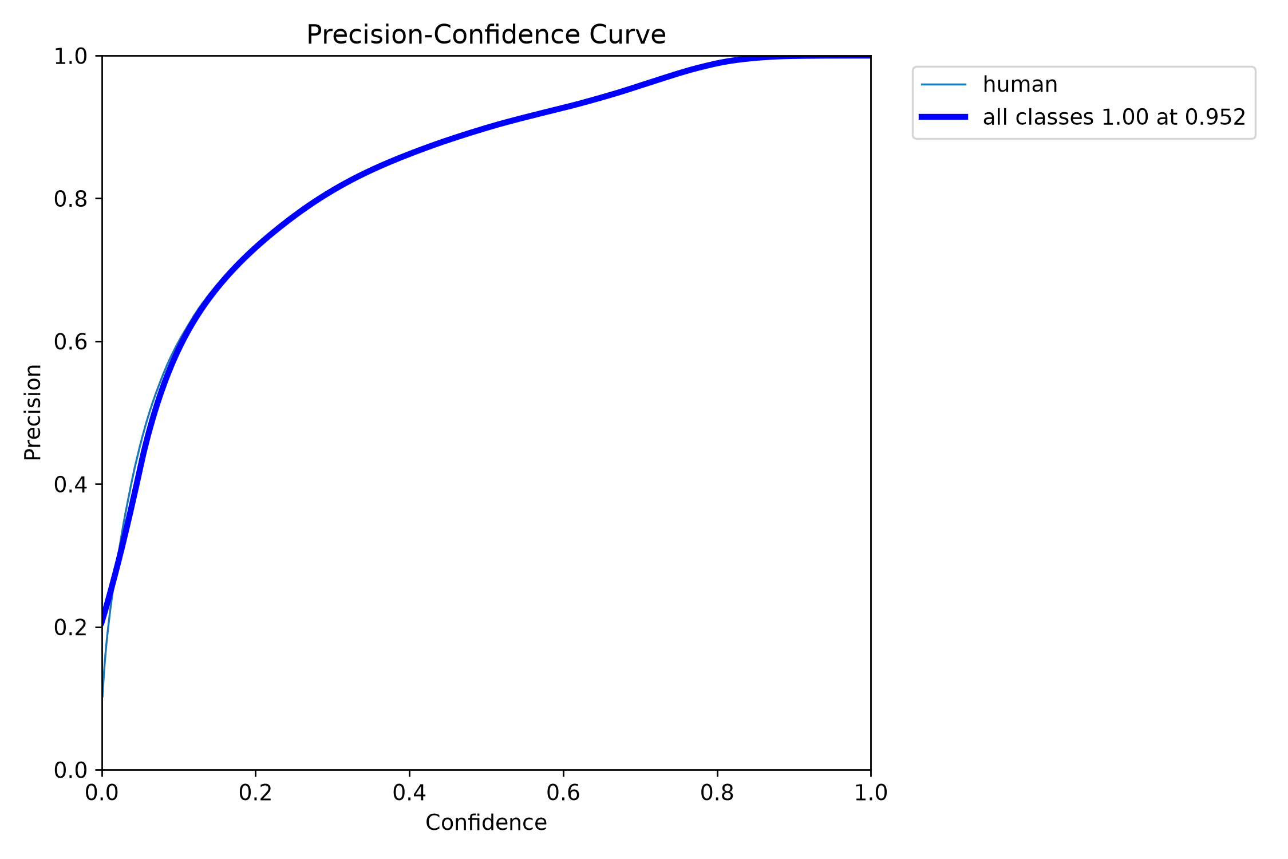
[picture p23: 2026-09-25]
Software/AI model/Trained_YOLOV8s/BoxP_curve.png

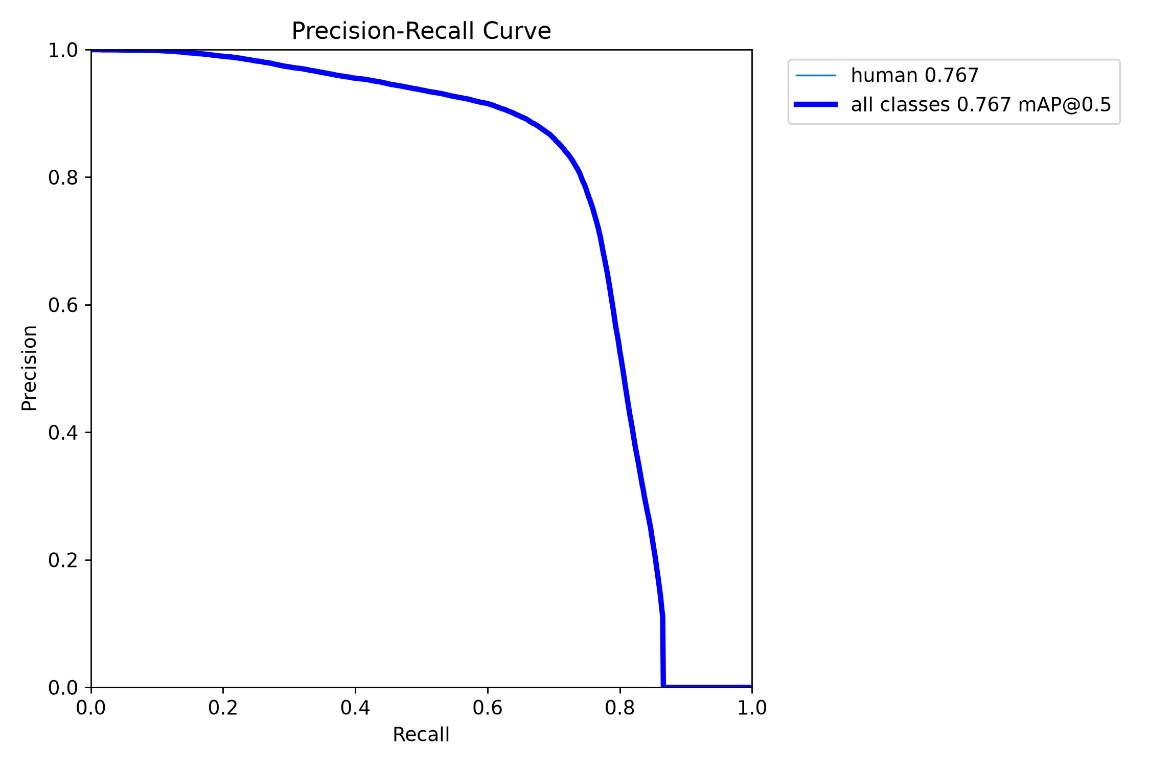
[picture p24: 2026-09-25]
Software/AI model/Trained_YOLOV8s/BoxPR_curve.png

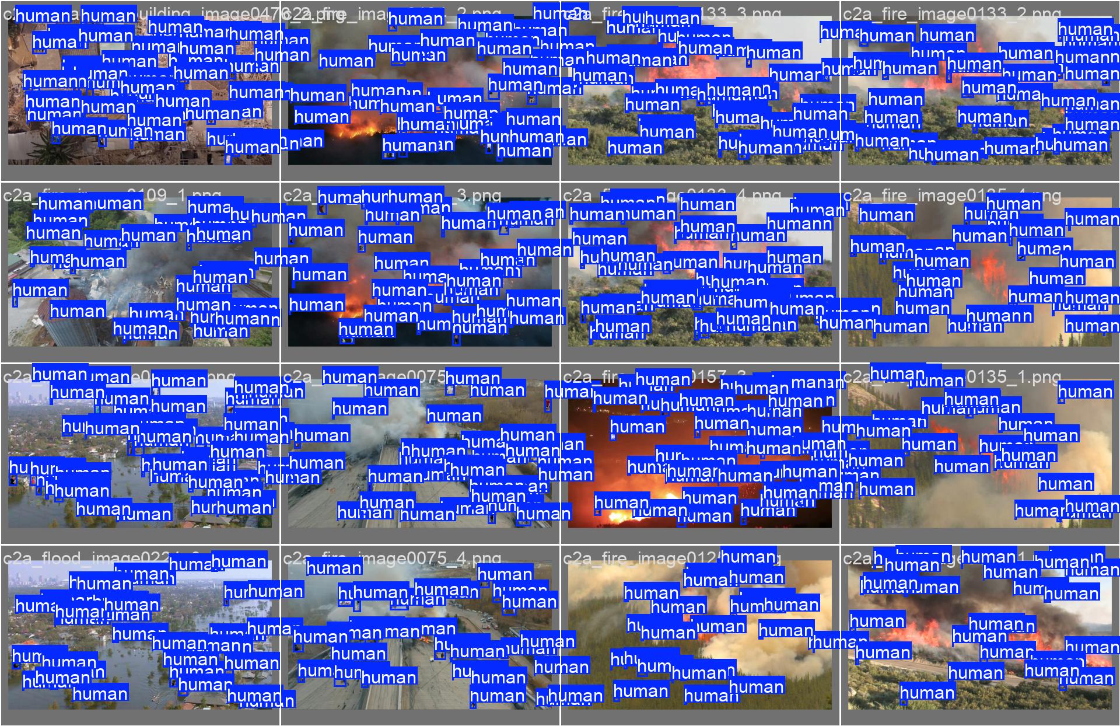
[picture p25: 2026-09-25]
Software/AI model/Trained_YOLOV8s/val_batch2_labels.jpg

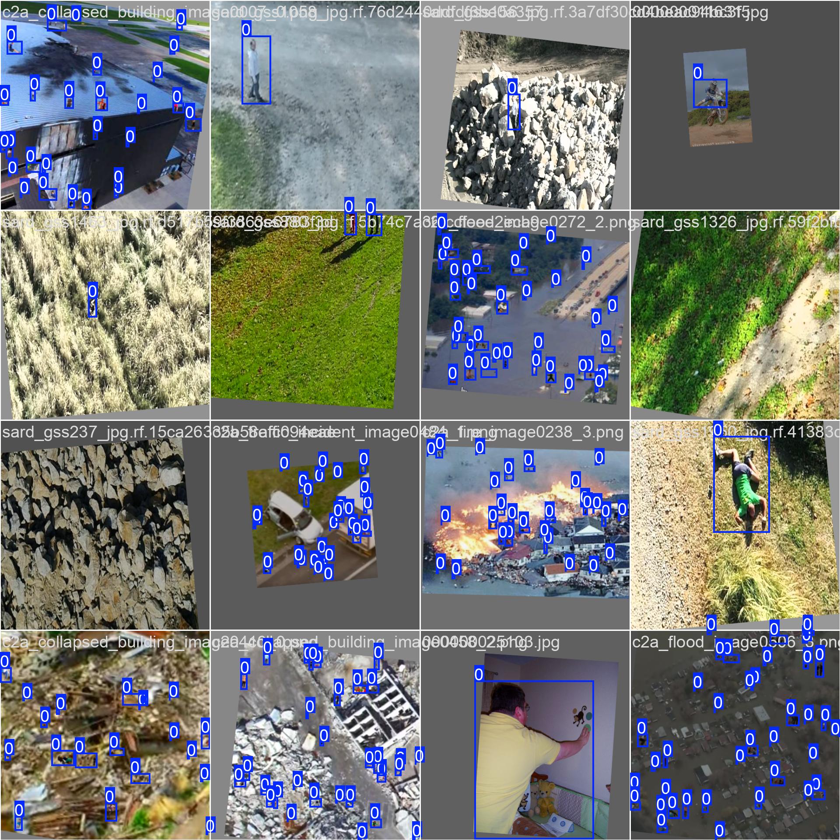
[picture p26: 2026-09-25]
Software/AI model/Trained_YOLOV8s/train_batch37082.jpg

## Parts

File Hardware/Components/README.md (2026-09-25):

# AERONEX Components

This folder contains the hardware component specifications and datasheets used in the AERONEX search and rescue quadcopter.

## Main Components

- Pixhawk 2.4.8 Flight Controller
- 4 × 920KV BLDC Motors
- 4 × AIR GEAR 450 ESCs
- 4 × T1045 Propellers
- Custom Li-Ion Battery
- Power Distribution / Power Module
- NEO-M10 GPS
- Compass
- 3DR 433MHz Telemetry
- Flysky Radio Transmitter and Receiver

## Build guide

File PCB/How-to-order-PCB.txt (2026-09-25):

How to Order PCB

Please refer to:
https://docs.easyeda.com/en/PCB/Order-PCB

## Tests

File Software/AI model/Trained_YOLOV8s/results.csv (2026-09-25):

epoch | time | train/box_loss | train/cls_loss | train/dfl_loss | metrics/precision(B) | metrics/recall(B) | metrics/mAP50(B) | metrics/mAP50-95(B) | val/box_loss | val/cls_loss | val/dfl_loss | lr/pg0 | lr/pg1 | lr/pg2
1 | 203.527 | 2.10112 | 1.43603 | 1.1686 | 0.60686 | 0.48845 | 0.45419 | 0.1978 | 2.06837 | 2.3134 | 1.30935 | 0.00332524 | 0.00332524 | 0.0700728
2 | 410.392 | 2.03445 | 1.3275 | 1.14596 | 0.73258 | 0.57356 | 0.59827 | 0.29058 | 1.83488 | 1.228 | 1.17866 | 0.00659266 | 0.00659266 | 0.0400069
3 | 611.446 | 1.97863 | 1.27656 | 1.12794 | 0.72759 | 0.56437 | 0.58509 | 0.28522 | 1.85201 | 1.40538 | 1.19347 | 0.00979407 | 0.00979407 | 0.00987498
4 | 809.896 | 1.92243 | 1.23158 | 1.11316 | 0.75687 | 0.60894 | 0.63606 | 0.33523 | 1.68832 | 1.08407 | 1.13834 | 0.009703 | 0.009703 | 0.009703
5 | 1010.01 | 1.89899 | 1.20457 | 1.10143 | 0.72544 | 0.57307 | 0.58758 | 0.28532 | 1.79077 | 1.24987 | 1.14143 | 0.009604 | 0.009604 | 0.009604
6 | 1209.55 | 1.85457 | 1.15408 | 1.08395 | 0.75199 | 0.58155 | 0.61315 | 0.30714 | 1.79624 | 1.28119 | 1.16208 | 0.009505 | 0.009505 | 0.009505
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

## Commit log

2026-09-25 Hardware/ ├── README.md └── Circuit_Diagram/ └── README.md
2026-09-25 Create PCB
2026-09-25 Create PCB folder
2026-09-25 Add PCB Gerber fabrication files
2026-09-25 Add circuit diagram
2026-09-25 All the files used in NIRMAAN
    Initial commit
    [best.ncnn.param, best.pnnx.param, results.csv]
